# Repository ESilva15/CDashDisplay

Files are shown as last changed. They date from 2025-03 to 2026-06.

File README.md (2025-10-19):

# CDashDisplay
The 'C' is for Cheap.

This project uses a cheap yellow display (ESP32-8048S043) as its foundation. It
can be acquired for round 30-40€ on Aliexpress, for example.

Currently I have a way to mount it on a G29 because its what I have.

To drive it I one of my other projects: [ESDI](https://github.com/ESilva15/ESDI)

## Many thanks
- to [mgaman/ESP32-4827S043-LVGL](https://github.com/mgaman/ESP32-4827S043-LVGL): 
don't remember exactly how but it helped me understand how to set up this ESP32
for development.

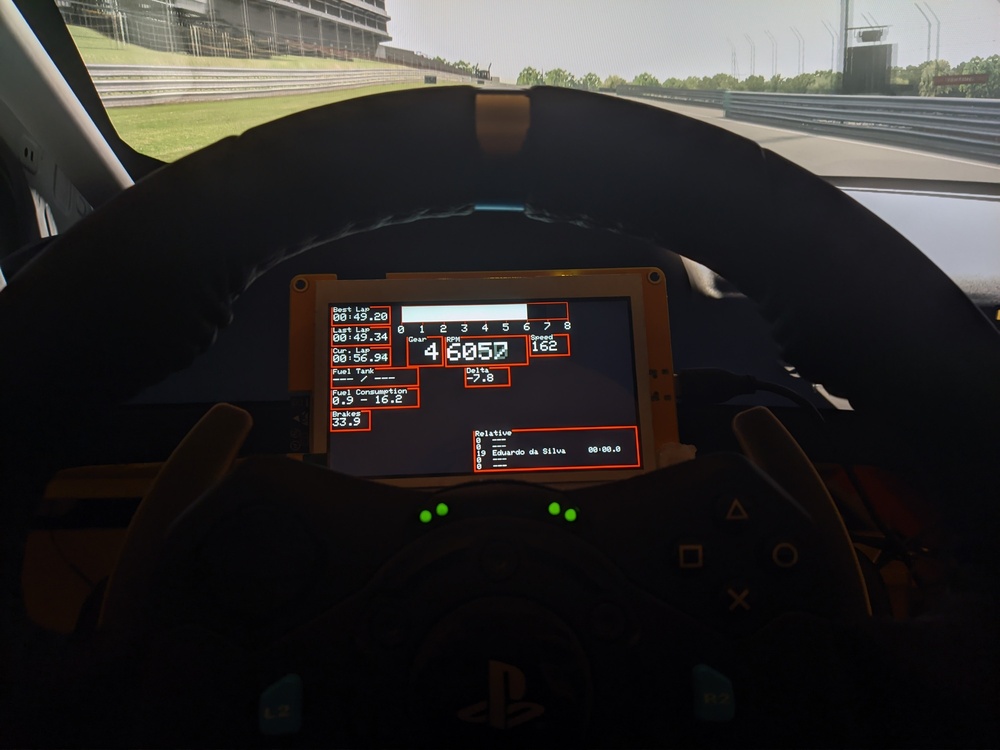
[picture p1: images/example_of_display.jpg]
example of the display


## Assembly
It requires a very simple modification to the G29. The display will seat between
the base and the steering wheel and for the stock G29 paddles to remain functional,
the steering wheel must be spaced.

I used simple spacers that I had laying around with OD≃8mm and ID≃5mm. They will
go on the screws that screw the wheel to the base:
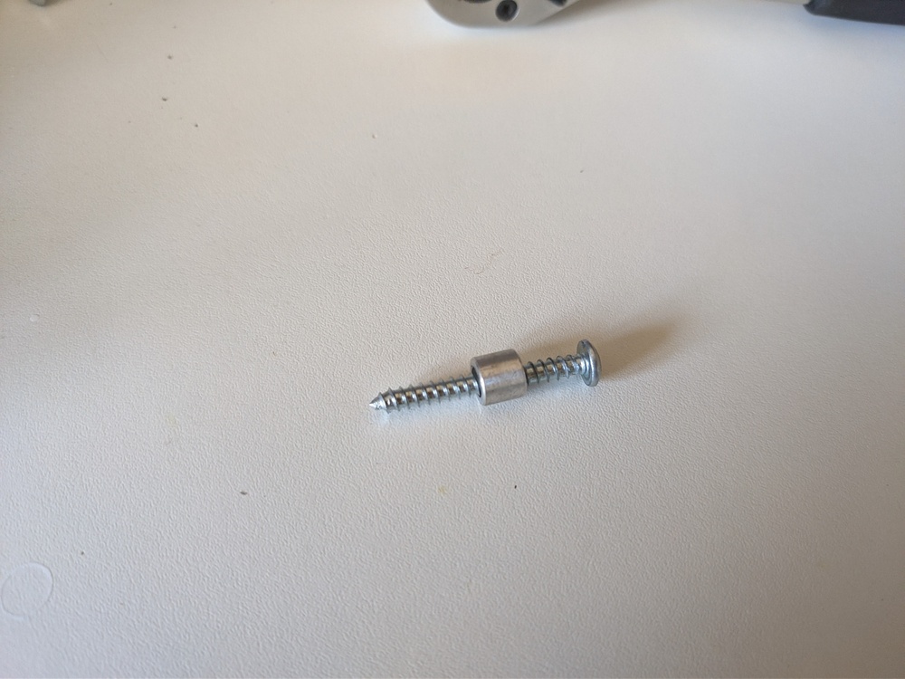
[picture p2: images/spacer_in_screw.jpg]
example of the display spacer in the screw

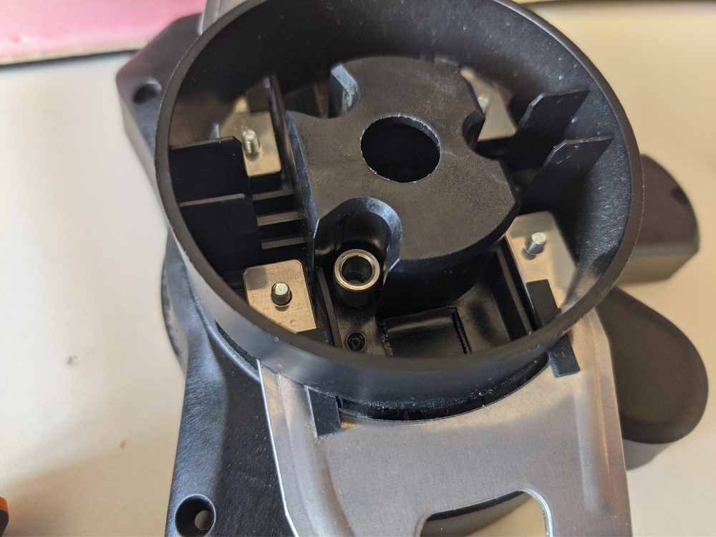
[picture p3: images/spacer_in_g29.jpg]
example of the display spacer in the g29


# Roadmap
- [ ] Simhub support
- [ ] Better layout tooling
- [ ] Dynamic layout/data

### Development
#### Debugging wires
| CYD | Serial Cable |
| --- | --- |
| Yellow [RX 18] | Green |
| Blue [TX 19] | White |

The `RX18` and `TX19` pins are the `IO18` and `IO19` pins on the board and 
probably are labeled as `UART1` and `USB`.

This is the `Serial2` we define on `main.cpp` currently.
Then we listen to it with something like ``.

### Cool fonts I like:
- u8g2_font_bubble_tr (really cool for splash screens)
- u8g2_font_helvR10_tr (very readable, should really try this one)
- u8g2_font_6x12_tf (monospace)

### Weird font rendering stuff going on
When the cursor is set to a position, the text will actually render
from the left bottom corner, so 0,0 will actually render text that
can't be viewed.
Solution, for now:
```cpp
U8G2 u8g2;
u8g2.setFont(u8g2_font_9x18_tf);
int ascent = u8g2.getAscent();
// will probably vary from font to font tho, right now I'm using
// monospace and that's enough
```

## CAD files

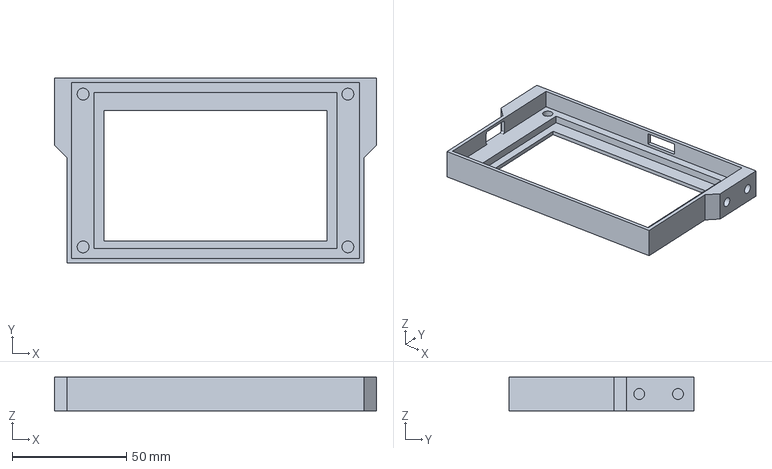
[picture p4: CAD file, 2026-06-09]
Case/fascia.FCStd
141.2 x 81.1 x 14.8 mm

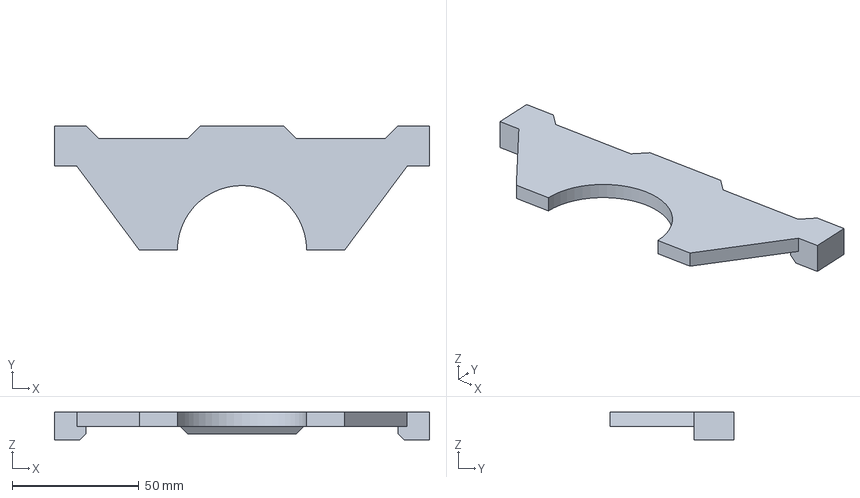
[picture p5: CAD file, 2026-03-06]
G29Mount/magneticG29Mount.FCStd
148.0 x 49.1 x 11.0 mm

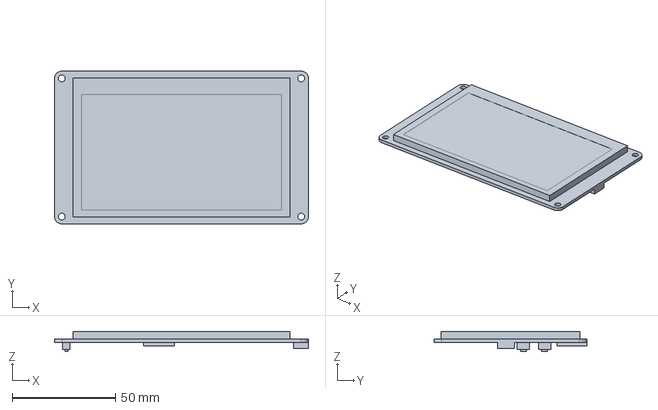
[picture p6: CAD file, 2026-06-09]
Case/display.FCStd
123.2 x 74.1 x 9.80 mm

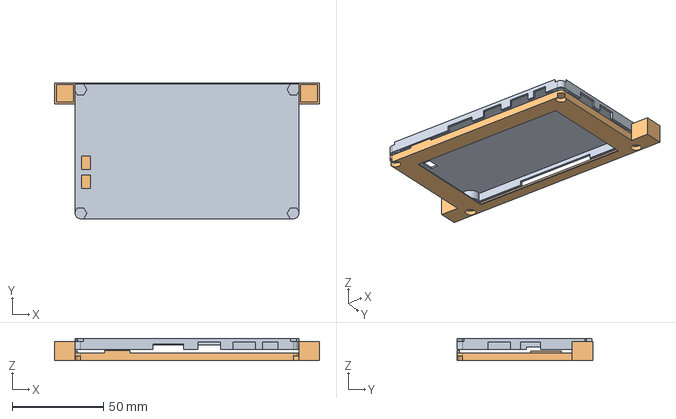
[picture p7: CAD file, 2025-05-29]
G29Mount/esp32Case_rear.FCStd
145.6 x 74.5 x 12.2 mm
rear
front

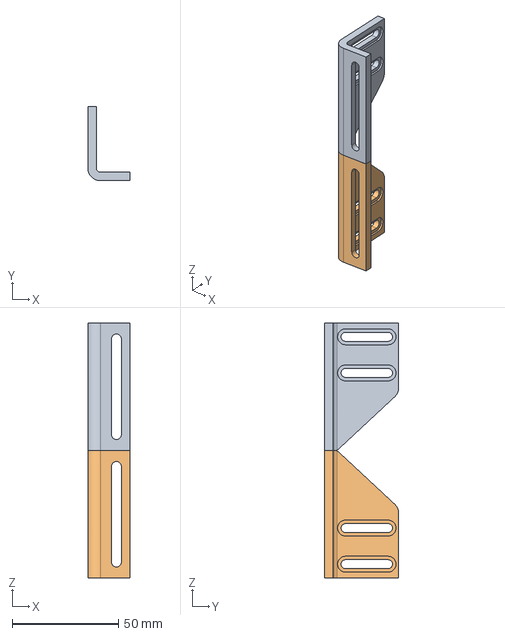
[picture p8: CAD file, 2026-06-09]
Case/mount_point_display_attachement.FCStd
20.0 x 35.0 x 120.0 mm
attachement
attachement (Mirror #1)

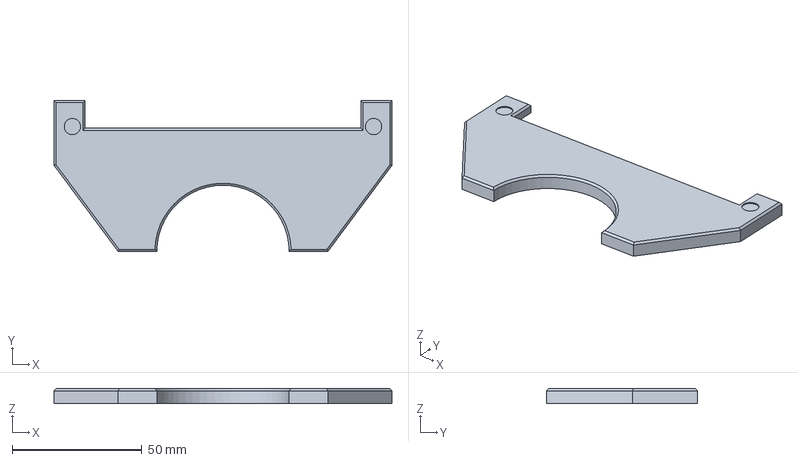
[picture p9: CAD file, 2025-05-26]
G29Mount/g29Mount.FCStd
130.4 x 58.2 x 5.60 mm

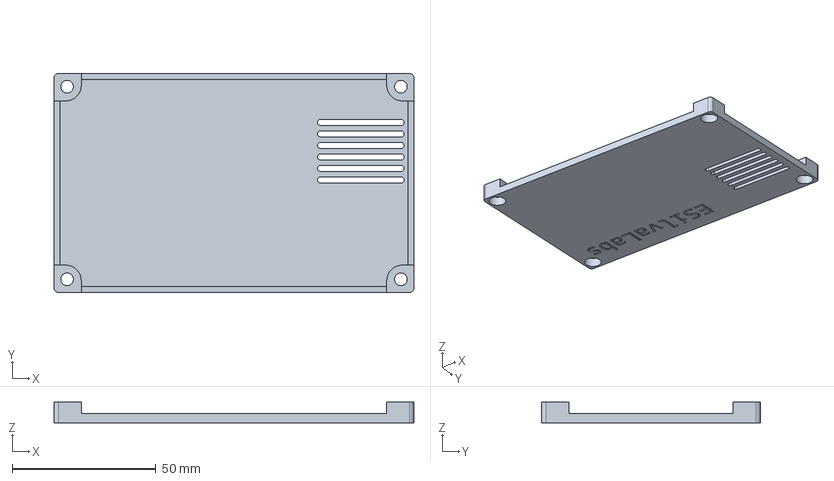
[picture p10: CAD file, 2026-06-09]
Case/cover.FCStd
125.2 x 76.1 x 7.25 mm

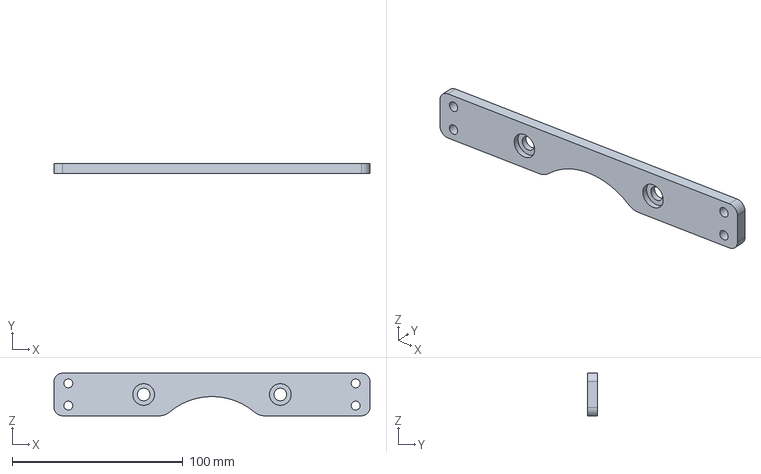
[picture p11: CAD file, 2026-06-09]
Case/mount_point.FCStd
185.0 x 6.00 x 25.0 mm

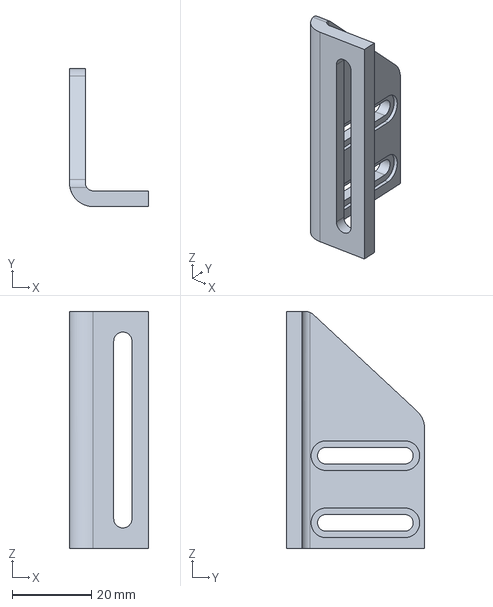
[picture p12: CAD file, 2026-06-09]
Case/mount_point_display_attachement_right_side.FCStd
20.0 x 35.0 x 60.0 mm

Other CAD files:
Case/mount_assembly.FCStd
Case/display_mount_assembly.FCStd
Case/assembly.FCStd

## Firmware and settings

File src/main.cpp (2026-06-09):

/*
ESP32-8048S043 based DashDisplay for simracing and stuff
by Eduardo Silva and others

TODO:
- Add a better communication mechanism that allows the desktop interface
to have more ways to run analytics
*/

#include "Arduino_GFX.h"
#include "HardwareSerial.h"
#include "UIComponent.h"
#include "UIDecorations.h"
#include "UIDimensions.h"
#include "UIDrawing.h"
#include "UIScreen.h"
#include "communication/commands.h"
#include "communication/packets.h"
#include "communication/walkieTalkie.h"
#include "logger.h"
#include "values.h"
#include "windowPool.h"
#include "methods/methods.h"
// #include "UIDrawing.h"
#include "UIString.h"
// #include "UITable.h"
#include "displaySetup.h"
#include "esp32-hal-psram.h"
// #include "ui.h"
#include <Arduino.h>
#include <Arduino_GFX_Library.h>
#include <cstdint>
#include <cstring>
#include <unistd.h>
// #include <nvs.h>
// #include <nvs_flash.h>

#define ESLABS_DEVICE_ID 0x01
#define ESLABS_DEVICE_NAME "ESLabs CDashDisplay"

#define UART1_TX 19
#define UART1_RX 18

Arduino_ESP32RGBPanel *panel = new Arduino_ESP32RGBPanel(
    40 /* DE */, 41 /* VSYNC */, 39 /* HSYNC */, 42 /* DCLK */, 45 /* R0 */,
    48 /* R1 */, 47 /* R2 */, 21 /* R3 */, 14 /* R4 */, 5 /* G0 */, 6 /* G1 */,
    7 /* G2 */, 15 /* G3 */, 16 /* G4 */, 4 /* G5 */, 8 /* B0 */, 3 /* B1 */,
    46 /* B2 */, 9 /* B3 */, 1 /* B4 */, 0 /*hsync_polarity*/,
    8 /* hsync_front_porch*/, 4 /* hsync_pulse_width*/,
    43 /* hsync_back_porch*/, 0 /*vsync_polarity*/, 8 /*vsync_front_porch*/,
    4 /*vsync_pulse_width*/, 12 /*vsync_back_porch*/, 1 /*pclk_active_neg*/,
    16000000 /*prefer_speed*/, false /*useBigEndian*/, 0 /*de_idle_high*/,
    0 /*pclk_idle_high*/
);

//
Arduino_GFX *gfx = new Arduino_RGB_Display(TFT_HOR_RES, TFT_VER_RES, panel, 16);

Curses::Screen mainScreen(gfx, UIDimensions(0, 0, TFT_HOR_RES, TFT_VER_RES),
                          UIDecorations());

// UIelements
// UIDecorations *gearTextDecor = new UIDecorations();
// UIString gearText(gfx, UIDimensions(0, 0, 0, 0), gearTextDecor, (char
// *)"Gear");
//
// UIElement mainWindow(
//     gfx,
//     UIDimensions(0, 0, TFT_HOR_RES, TFT_VER_RES),
//     gearTextDecor,
//     (char*)"MAIN WINDOW"
// );

void setup() {
  psramInit();
  Serial.begin(115200);

  // Initialize the debug serial object
  Logger::Initialize(UART1_RX, UART1_TX);

  LOG_INFO(F("=== ESP32 SimRacing DashDisplay ===\r\n"));
  LOG_INFO(F("* Initiating display\r\n"));

  initialDisplaySetup(gfx);

  // Only setup the main screen after initializing the Serial2
  mainScreen.Setup("Main Window");
  UIElement *mainWindow = mainScreen.mainWindowHandle;
  mainWindow->drawBox();

  delay(500);
  LOG_INFO(F("* Ready for loop"));
}

const uint16_t PayloadMax = 2056;
uint8_t payload[PayloadMax] = {0};
char lineBuffer[64]; // Enough for "XX XX XX XX XX XX XX XX "
                     //
void print_memory_stats() {
    multi_heap_info_t info;
    
    // MALLOC_CAP_8BIT ensures we are looking at memory capable of 
    // storing data (Internal RAM + PSRAM if available)
    heap_caps_get_info(&info, MALLOC_CAP_8BIT);

    size_t total_free = info.total_free_bytes;
    size_t total_allocated = info.total_allocated_bytes;
    size_t total_size = total_free + total_allocated;
    size_t min_free = info.minimum_free_bytes; // "Low water mark"

    LOG_INFO(F("Memory Stats:\r\n"));
    LOG_INFO(F("  Total:     %u bytes\r\n"), total_size);
    LOG_INFO(F("  Used:      %u bytes\r\n"), total_allocated);
    LOG_INFO(F("  Free:      %u bytes\r\n"), total_free);
    LOG_INFO(F("  Min Free:  %u bytes (Historic peak usage)\r\n"), min_free);
}

void loop(void) {
  uint64_t cur = millis();

  Command cmd = CmdUnknown;

  if (Serial.available() > 0) {
    int16_t resp = WalkieTalkie::RecvStream(&cmd, payload, PayloadMax);
    if (resp < 0) {
      LOG_WARN(F("Failed to receive data from serial"));
      return;
    } else if (resp == 0) {
      LOG_INFO(F("No data to receive\r\n"));
      return;
    }

    LOG_DEBUG(F("Command: %s\n"), CommandToStr(cmd));
    LOG_DEBUG(F("Response Payload Len: %d\n"), resp);

    // print_memory_stats();

    switch(cmd) {
      case CmdRequestID:
        IdentificationPacket papers;
        initIdentificationPacket(&papers, ESLABS_DEVICE_NAME, ESLABS_DEVICE_ID); 
        WalkieTalkie::SendData(&papers);
        break;
      case CmdCreateWindow: {
        int8_t newWindowID = Window::Create(payload, &mainScreen);
        if (newWindowID < 0) {
          LOG_WARN(F("Failed to add new window!\n"));
          break;
        }

        LOG_INFO(F("Successfully added a new window: %d\n"), newWindowID);

        // Now we return the ID of this new window - esdi should expect it
        WindowIDReply wID;
        initWindowIDReply(&wID, newWindowID);
        WalkieTalkie::SendData(&wID);

        break;
      }
      case CmdUpdateWinDims: {
        LOG_INFO(F("Updating Win DIMS\n"));
        bool res = Window::UpdateDims(payload, &mainScreen);
        if (!res) {
          LOG_WARN(F("Failed to update window dims\n"));
        }
        break;
      };
      case CmdUpdateWin: {
        LOG_INFO(F("UPDATEING WINDOW\n")); 
        bool res = Window::UpdateWindow(payload, &mainScreen);
        if (!res) {
          LOG_WARN(F("Failed to update window\n"));
        }
        break; 
      }      
      case CmdDestroyWindow: {
        uint8_t destroyedWinID = Window::Destroy(payload, &mainScreen);
        if (destroyedWinID < 0) {
          LOG_WARN(F("Failed to destroy window\n"));
          break;
        }

        LOG_INFO(F("Succesfully destroyed window: %d\n"), destroyedWinID);

        break;
      }
      case CMDData: {
        LOG_DEBUG(F("Data Received: %d bytes\r\n"), resp);
        
        int pos = 0;
        
        for (int k = 0; k < resp; k++) {
            // Write 2 hex digits and a space to our local buffer
            // %02X ensures leading zeros (e.g., 0A instead of A)
            pos += sprintf(lineBuffer + pos, "%02X ", payload[k]);
        
            // Every 8 bytes OR if it's the very last byte in the payload
            if ((k + 1) % 8 == 0 || k == resp - 1) {
                // Send the completed line to the logger
                // We use LOG_DEBUG or similar so we don't spam [WARN] on every line
                LOG_DEBUG(F("%s\r\n"), lineBuffer);
                
                // Reset buffer position for the next line
                pos = 0;
                memset(lineBuffer, 0, sizeof(lineBuffer));
            }
        }
        LOG_DEBUG(F("\r\n"));

        Data::Parse(payload, resp, &mainScreen);

        break;
      }
      default:
        LOG_WARN(F("Unknown Command: `%d` has not been implemented yet."), cmd);
    }
  }
}

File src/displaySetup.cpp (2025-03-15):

#include "displaySetup.h"
#include "UIDrawing.h"
#include "esp32-hal-ledc.h"
#include <Arduino.h>
#include <Arduino_GFX.h>

void setBrightness(uint32_t value, uint32_t valueMax) {
  uint32_t duty = (4095 / valueMax) * min(value, valueMax);
  ledcWrite(BRIGHTNESS_CHANNEL, duty);
}

void backlightSetup() {
  ledcSetup(BRIGHTNESS_CHANNEL, PWM_FREQUENCY, PWM_RESOLUTION);
  ledcAttachPin(TFT_BL, BRIGHTNESS_CHANNEL);
  setBrightness(DEFAULT_BRIGHTNESS);
}

void initialDisplaySetup(Arduino_GFX *gfx) {
  gfx->begin();
  // gfx->setFont(u8g2_font_9x18_tf);

  // Set screen & touch to the same rotation
  gfx->setRotation(SCREEN_ORIENTATION);
  backlightSetup();
  gfx->fillScreen(MAIN_BG_COLOR);
  gfx->setTextColor(MAIN_FG_COLOR);
}

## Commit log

2025-04-21 added brake bias
2025-05-20 Added the G29 base mount for the display and the tacho BAR
    [g29Mount.FCStd]
2025-05-26 cube magnets mount
    [esp32Case_rear.FCStd, g29Mount.FCStd, magneticG29Mount.FCStd]
2025-05-29 Added a magnetic mount
    Its still pretty shit:
    - the screw holes on the shell don't line up
    - the shell bows due to the screw disalignment stress
    - the back of the shell hits the G29 wheel base, needs some coercion
    [esp32Case_rear.FCStd, magneticG29Mount.FCStd]
2025-10-29 Simply added an ID to the device
2025-12-31 Fixed teh window create method
    [main.cpp]
2026-03-06 update to the g29 mount
    [magneticG29Mount.FCStd]
2026-03-10 Implementing the data parsing approach
    I'm receiving data in a very specific format for each data type.
    I parse the bytes correctly and hopefully everything works, yo.
    [main.cpp]
2026-06-09 added the moza R9 case
    [assembly.FCStd, cover.FCStd, display.FCStd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]
